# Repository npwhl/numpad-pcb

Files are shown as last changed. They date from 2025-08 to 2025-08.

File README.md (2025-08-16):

# 6x4 USB-C Numpad PCB
A PCB for a 6x4 numpad with a row for four customizable macros. Uses Alps switch footprints and a USB-C connection. Designed in Kicad.    

TBA: an image of the final PCB in person! :-)   
Gif of the PCB    
TBA: link to firmware repository   

# The Design
_A schematic of the MCU connections._  
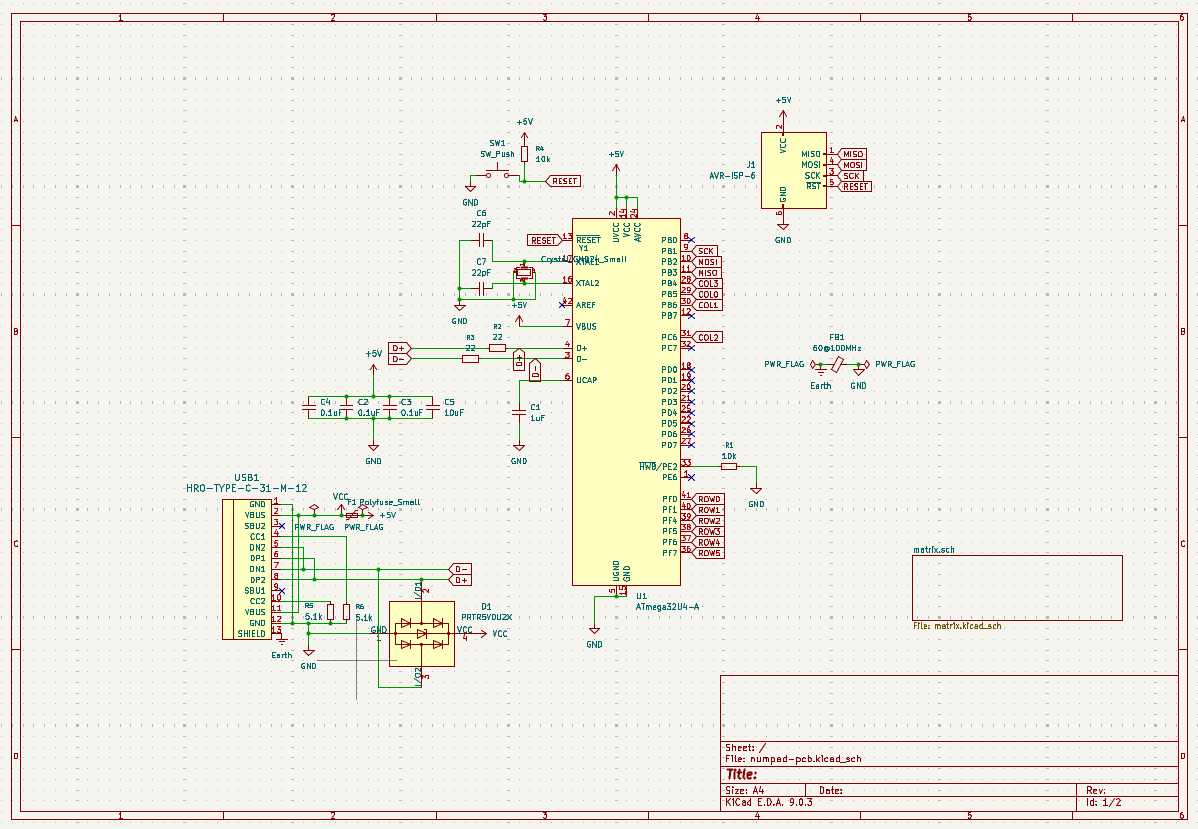
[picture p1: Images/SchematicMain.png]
Schematic of the MCU


_A schematic of the matrix of switch connections._    
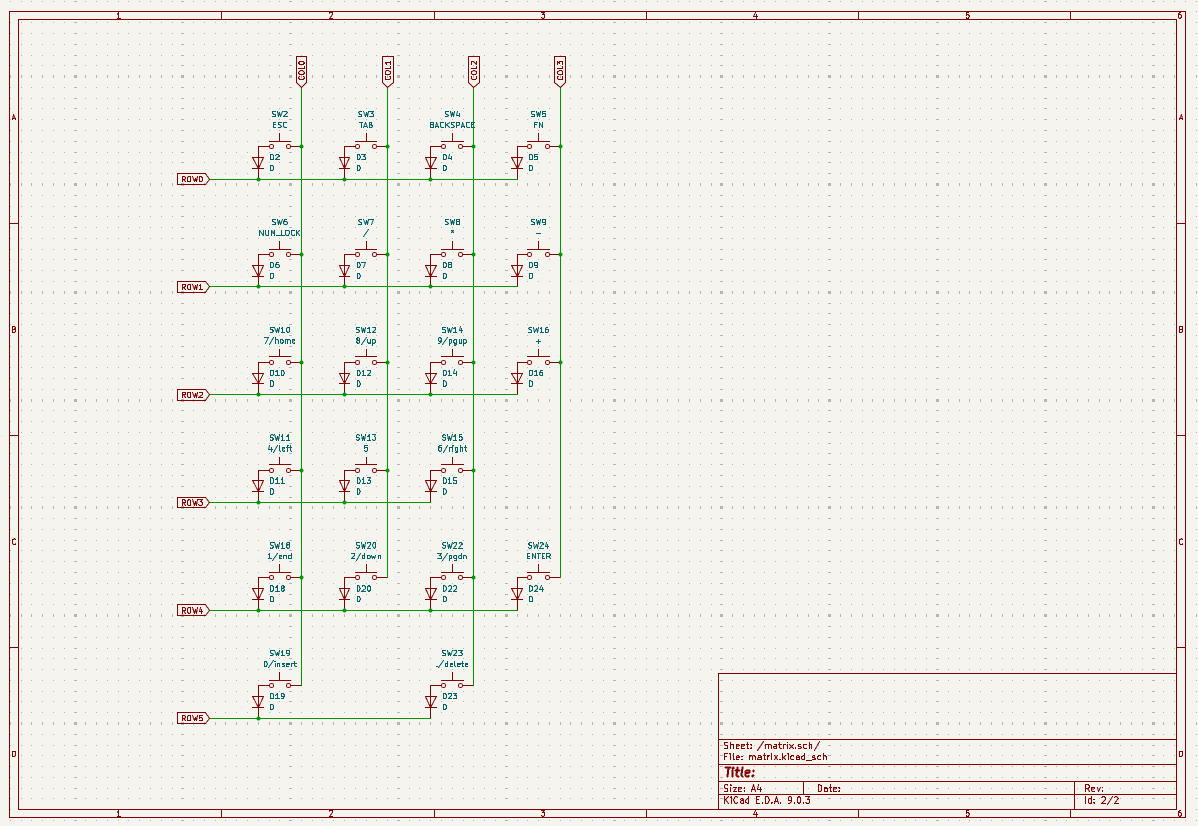
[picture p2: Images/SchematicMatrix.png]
Schematic of the Switches Matrix
   

_The front traces of the PCB._      
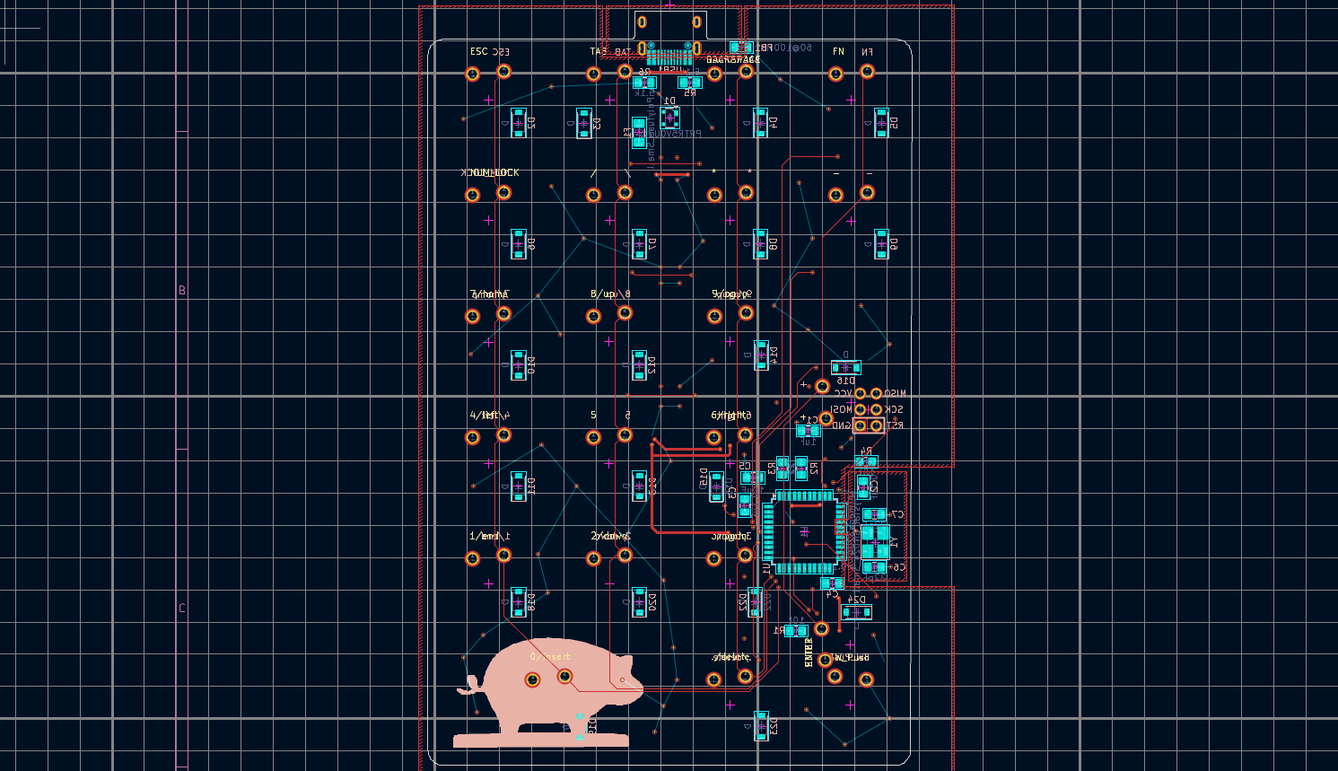
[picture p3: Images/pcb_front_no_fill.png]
     

_The back traces of the PCB._      
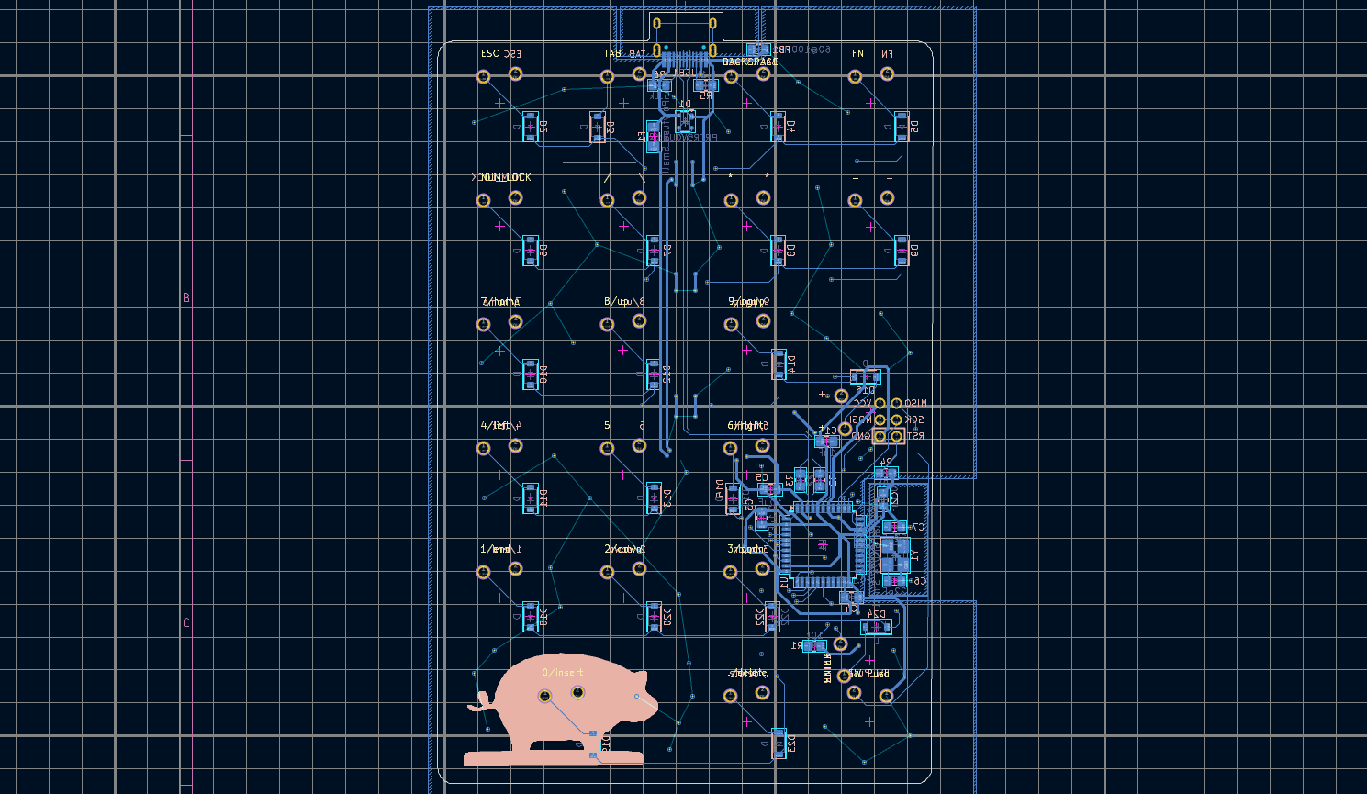
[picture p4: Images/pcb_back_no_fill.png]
     

# How It Was Made
**Software:** Kicad EDA v9.03  
**Manufacturer:** TBA  
This numpad uses the following bill of materials:    
| Designation | Type | Footprint | Quantity |
|---|---|---|---|
| FB1 | Ferrite Bead | 0805 | 1 |
| SW1 | Reset switch | SKQG | 1 |
| SW2-SW23 | Reset switch | ALPS | 22 |
| C1-C4 | 100nF Capacitor | 0805 | 4 |
| C5 | 10uF Capacitor | 0805 | 1 |
| C6 | 1uF Capacitor | 0805 | 1 |
| C7, C8 | 22pF Capacitor | 0805 | 2 |
| R1, R2 | 10kΩ Resistor | 0805 | 2 |
| R3, R4 | 22Ω Resistor | 0805 | 2 |
| R5, R6 | 5.1kΩ Resistor | 0805 | 2 |
| X1 | 16 MHz Crystal | 3225 | 1 |
| USB1 | USB Connector | HRO-TYPE-C-31-M-12 | 1  |
| U2 | PRTR5V0U2X | SOT143B | 1 |
| U1 | Atmega 32U4-AU | TQFP-44 | 1 |
| F1 | PTC Fuse | 1206 | 1 |
| D1-D23 | Diode | SOD-123 | 23 | 
   
The 3D modeling software Blender has many shortcuts that are only accessable using numpad shortcuts. Although these features are also accessable on Blender's UI, these shortcuts greatly accelerate the modeling process. However, my partner's keyboard is 65% and lacks a numpad. I wanted to design him a numpad that could solve this problem while using the keycaps and Alps switches he currently had. I also wanted to design the numpad with USB-C conectivity and a 4-key macro row for any additional shortcuts.  
  
To make the numpad, I followed [Masterzen's tutorial](https://www.masterzen.fr/2020/05/03/designing-a-keyboard-part-1/) on designing a PCB for a keyboard. This was my first time designing a PCB and using software like Kicad. I initially struggled with laying out the components on the PCB. I learned a lot of new information about why PCB components are laid out in specific ways and how to handle signals with minimal noise. I also learned about the importance of impedance on especially delicate routes such as the USB-C's D+/D- differential pair. In the future, I would like to optimize routing as much as possible with minimal vias. The amount of traces and their angles around the MCU are somewhat difficult to read and has the potential to create too much noise around the critical differential pairs. Since this is a low-speed numpad, this will most likely not be an issue, but I want to prioritize reliable PCB design moving forward.
      
_The PCB as viewed in the 3D viewer._      
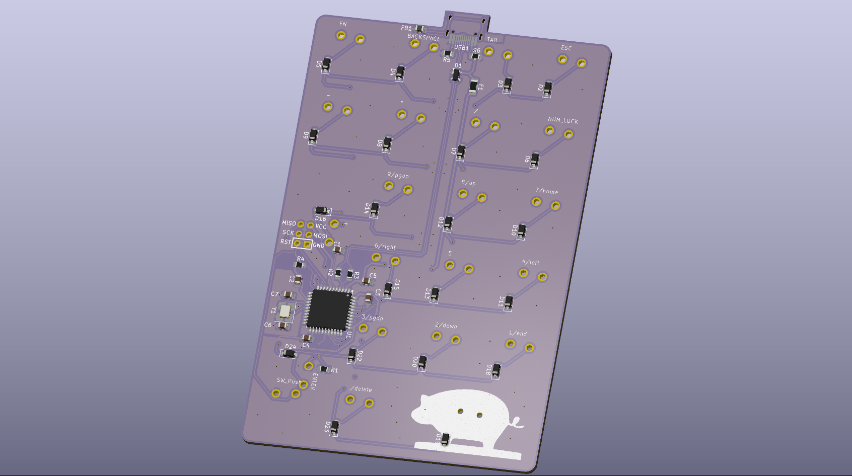
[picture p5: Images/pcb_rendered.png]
     

# To Do
This PCB is still in progress. The next steps are:  
1. Order PCB board and its components. 
2. Program the firmware using [QMK](https://github.com/qmk/qmk_firmware). 
3. Model a chassis for the numpad in Solidworks. 
4. Create a main repository where the final design is kept. 

# How to Build
If you want to build the numpad yourself, you can order the parts following the links on the bill of materials table above! You can also use the same manufacturer, or the following Kicad-recommended manufacturers:  
* [Alsier (US)](https://aisler.net/)
* [OSHPark (US)](https://docs.oshpark.com/design-tools/kicad/generating-kicad-gerbers/)
* [PCBWay (China)](https://www.pcbway.com/blog/help_center/Generate_Gerber_file_from_Kicad.html)

<sub><sup>PS: Thank you (bf's github user)!</sup></sub>

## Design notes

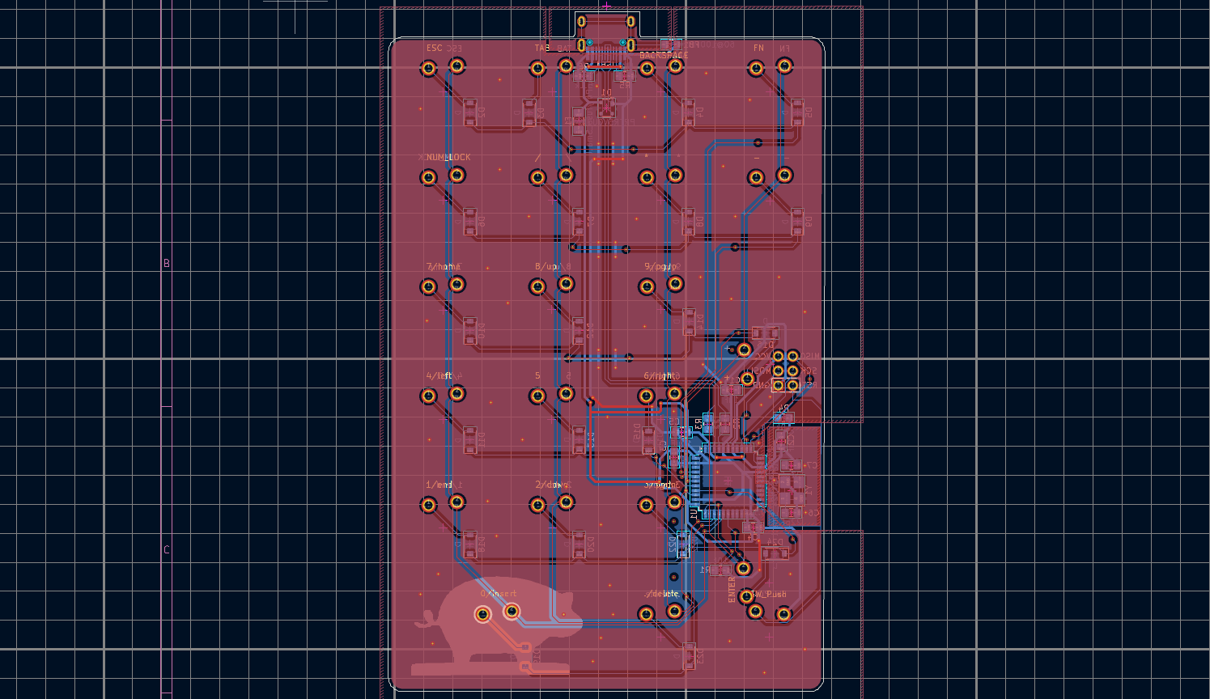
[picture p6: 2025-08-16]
Images/pcb_fill.png

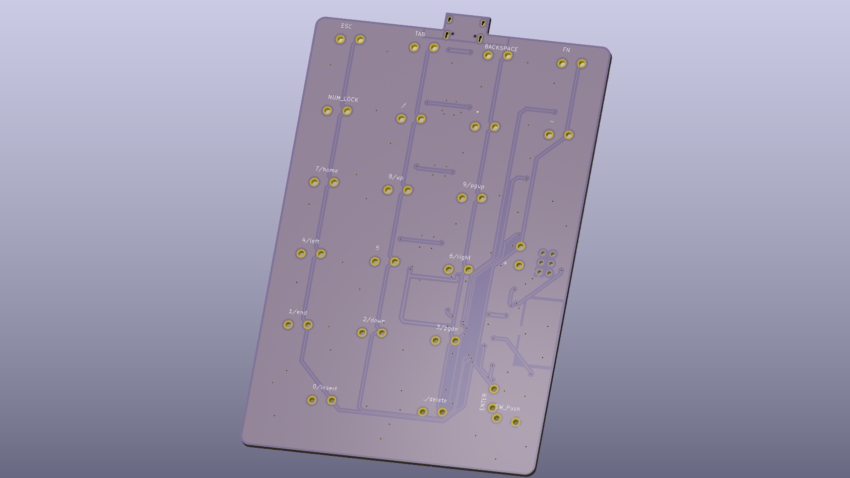
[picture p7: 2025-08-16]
Images/pcb_rendered_back.png

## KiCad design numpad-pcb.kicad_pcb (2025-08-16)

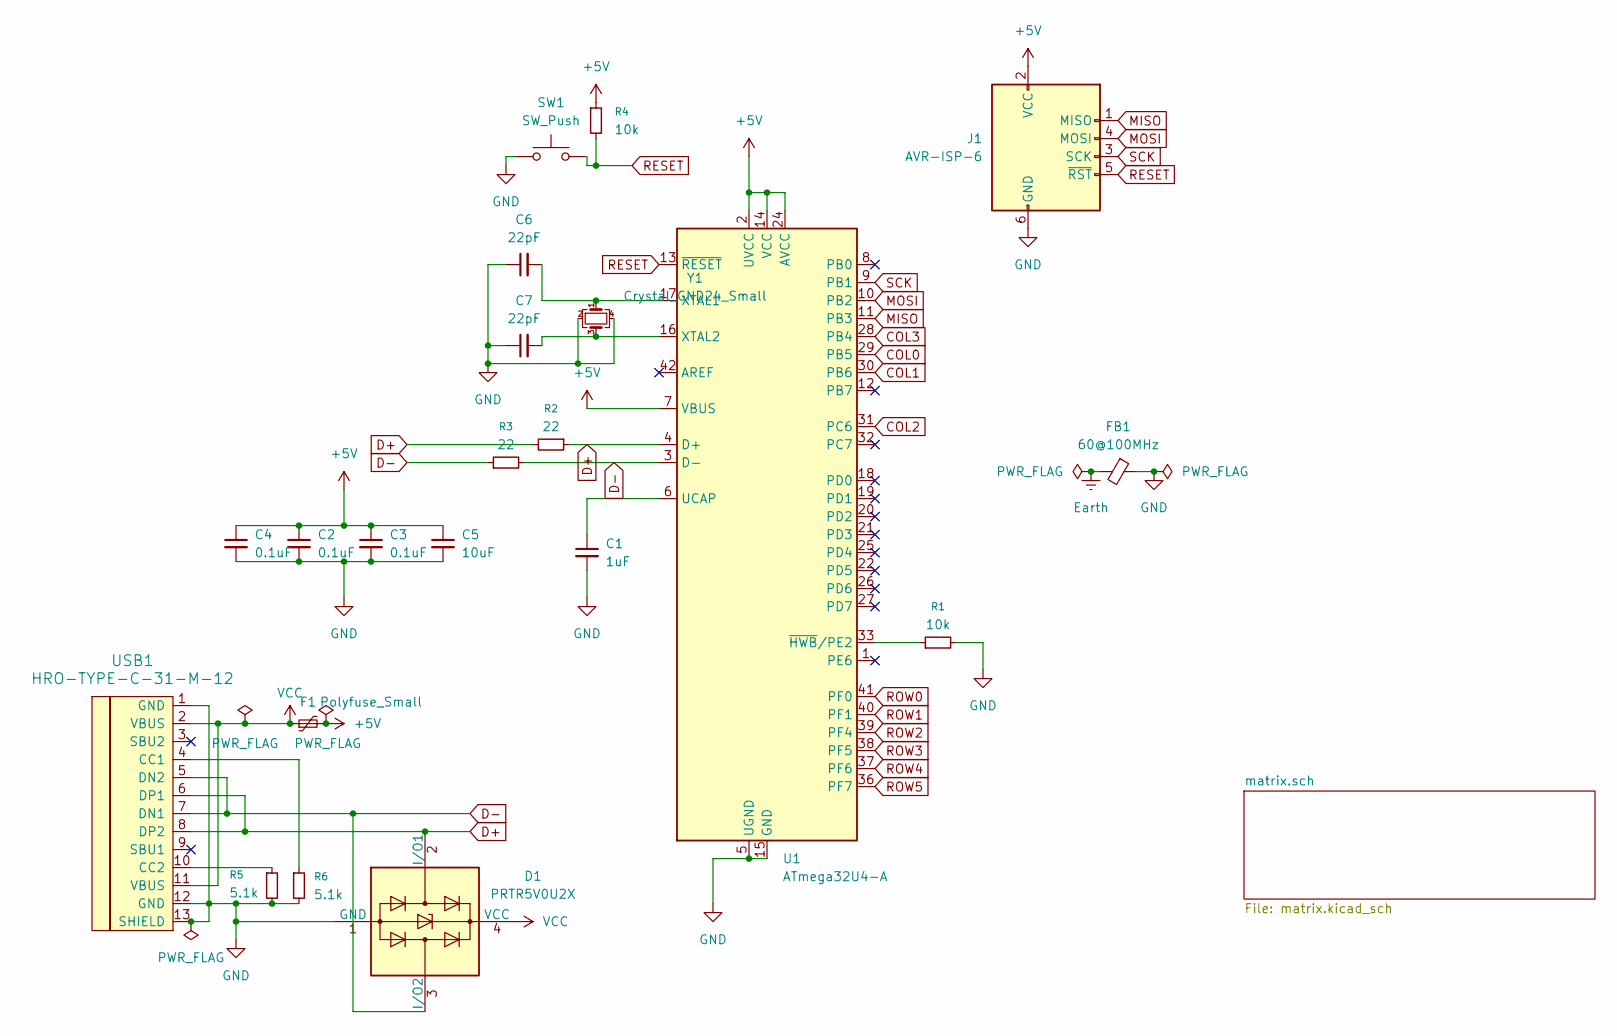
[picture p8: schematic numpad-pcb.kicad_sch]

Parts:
C1: 1uF; C_0805_2012Metric_Pad1.18x1.45mm_HandSolder
C2, C3, C4: 0.1uF; C_0805_2012Metric_Pad1.18x1.45mm_HandSolder
C5: 10uF; C_0805_2012Metric_Pad1.18x1.45mm_HandSolder
C6, C7: 22pF; C_0805_2012Metric_Pad1.18x1.45mm_HandSolder
D1: PRTR5V0U2X; SOT-143
F1: Polyfuse_Small; Fuse_1206_3216Metric_Pad1.42x1.75mm_HandSolder
FB1: 60@100MHz; L_0805_2012Metric_Pad1.15x1.40mm_HandSolder
J1: AVR-ISP-6; Reset_Pretty-Mask
R1, R4: 10k; R_0805_2012Metric_Pad1.20x1.40mm_HandSolder
R2, R3: 22; R_0805_2012Metric_Pad1.20x1.40mm_HandSolder
R5, R6: 5.1k; R_0805_2012Metric_Pad1.20x1.40mm_HandSolder
SW1: SW_Push; ALPS-1U
U1: ATmega32U4-A; TQFP-44_10x10mm_P0.8mm
USB1: HRO-TYPE-C-31-M-12; HRO-TYPE-C-31-M-12-HandSoldering
Y1: Crystal_GND24_Small; Crystal_SMD_3225-4Pin_3.2x2.5mm_HandSoldering

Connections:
+5V: C2.1, C3.1, C4.1, C5.1, F1.2, J1.2 (VCC), R4.1, U1.2 (UVCC), U1.7 (VBUS), U1.14 (VCC), U1.24 (AVCC), U1.34 (VCC), U1.44 (AVCC)
COL0: U1.29 (PB5); also elsewhere on the board
COL1: U1.30 (PB6); also elsewhere on the board
COL2: U1.31 (PC6); also elsewhere on the board
COL3: U1.28 (PB4); also elsewhere on the board
D+: D1.2 (I/O1), R2.1, R2.2, U1.4 (D+), USB1.6 (DP1), USB1.8 (DP2)
D-: D1.3 (I/O2), R3.1, R3.2, U1.3 (D-), USB1.5 (DN2), USB1.7 (DN1)
MISO: J1.1 (MISO), U1.11 (PB3)
MOSI: J1.4 (MOSI), U1.10 (PB2)
unnamed: C1.1, U1.6 (UCAP)
unnamed: C6.2, U1.17 (XTAL1), Y1.1
unnamed: C7.2, U1.16 (XTAL2), Y1.3
unnamed: R1.1, U1.33 (~HWB/PE2)
unnamed: R6.1, USB1.4 (CC1)
unnamed: R5.1, USB1.10 (CC2)
RESET: J1.5 (~RST), R4.2, SW1.2, U1.13 (~RESET)
ROW0: U1.41 (PF0); also elsewhere on the board
ROW1: U1.40 (PF1); also elsewhere on the board
ROW2: U1.39 (PF4); also elsewhere on the board
ROW3: U1.38 (PF5); also elsewhere on the board
ROW4: U1.37 (PF6); also elsewhere on the board
ROW5: U1.36 (PF7); also elsewhere on the board
SCK: J1.3 (SCK), U1.9 (PB1)
VCC: D1.4 (VCC), F1.1, USB1.2 (VBUS), USB1.11 (VBUS)

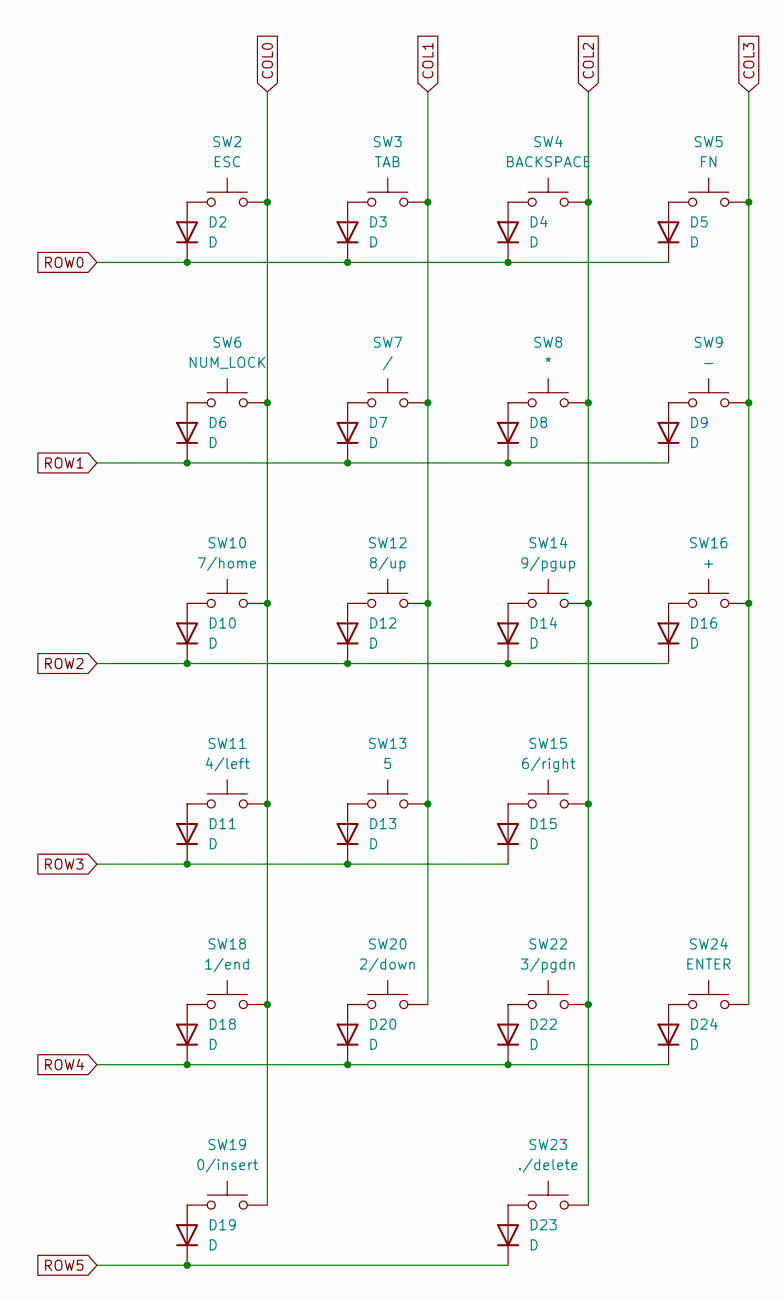
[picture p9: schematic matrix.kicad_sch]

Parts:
D2, D3, D4, D5, D6, D7, D8, D9, D10, D11, D12, D13, D14, D15, D16, D18, D19, D20, D22, D23, D24: D; D_SOD-123
SW2: ESC; ALPS-1U
SW3: TAB; ALPS-1U
SW4: BACKSPACE; ALPS-1U
SW5: FN; ALPS-1U
SW6: NUM_LOCK; ALPS-1U
SW7: /; ALPS-1U
SW8: *; ALPS-1U
SW9: -; ALPS-1U
SW10: 7/home; ALPS-1U
SW11: 4/left; ALPS-1U
SW12: 8/up; ALPS-1U
SW13: 5; ALPS-1U
SW14: 9/pgup; ALPS-1U
SW15: 6/right; ALPS-1U
SW16: +; ALPS-2U
SW18: 1/end; ALPS-1U
SW19: 0/insert; ALPS-2U
SW20: 2/down; ALPS-1U
SW22: 3/pgdn; ALPS-1U
SW23: ./delete; ALPS-1U
SW24: ENTER; ALPS-2U

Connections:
COL0: SW2.2, SW6.2, SW10.2, SW11.2, SW18.2, SW19.2; also elsewhere on the board
COL1: SW3.2, SW7.2, SW12.2, SW13.2, SW20.2; also elsewhere on the board
COL2: SW4.2, SW8.2, SW14.2, SW15.2, SW22.2, SW23.2; also elsewhere on the board
COL3: SW5.2, SW9.2, SW16.2, SW24.2; also elsewhere on the board
unnamed: D2.2 (A), SW2.1
unnamed: D3.2 (A), SW3.1
unnamed: D4.2 (A), SW4.1
unnamed: D5.2 (A), SW5.1
unnamed: D6.2 (A), SW6.1
unnamed: D7.2 (A), SW7.1
unnamed: D8.2 (A), SW8.1
unnamed: D9.2 (A), SW9.1
unnamed: D10.2 (A), SW10.1
unnamed: D11.2 (A), SW11.1
unnamed: D12.2 (A), SW12.1
unnamed: D13.2 (A), SW13.1
unnamed: D14.2 (A), SW14.1
unnamed: D15.2 (A), SW15.1
unnamed: D16.2 (A), SW16.1
unnamed: D18.2 (A), SW18.1
unnamed: D19.2 (A), SW19.1
unnamed: D20.2 (A), SW20.1
unnamed: D22.2 (A), SW22.1
unnamed: D23.2 (A), SW23.1
unnamed: D24.2 (A), SW24.1
ROW0: D2.1 (K), D3.1 (K), D4.1 (K), D5.1 (K); also elsewhere on the board
ROW1: D6.1 (K), D7.1 (K), D8.1 (K), D9.1 (K); also elsewhere on the board
ROW2: D10.1 (K), D12.1 (K), D14.1 (K), D16.1 (K); also elsewhere on the board
ROW3: D11.1 (K), D13.1 (K), D15.1 (K); also elsewhere on the board
ROW4: D18.1 (K), D20.1 (K), D22.1 (K), D24.1 (K); also elsewhere on the board
ROW5: D19.1 (K), D23.1 (K); also elsewhere on the board

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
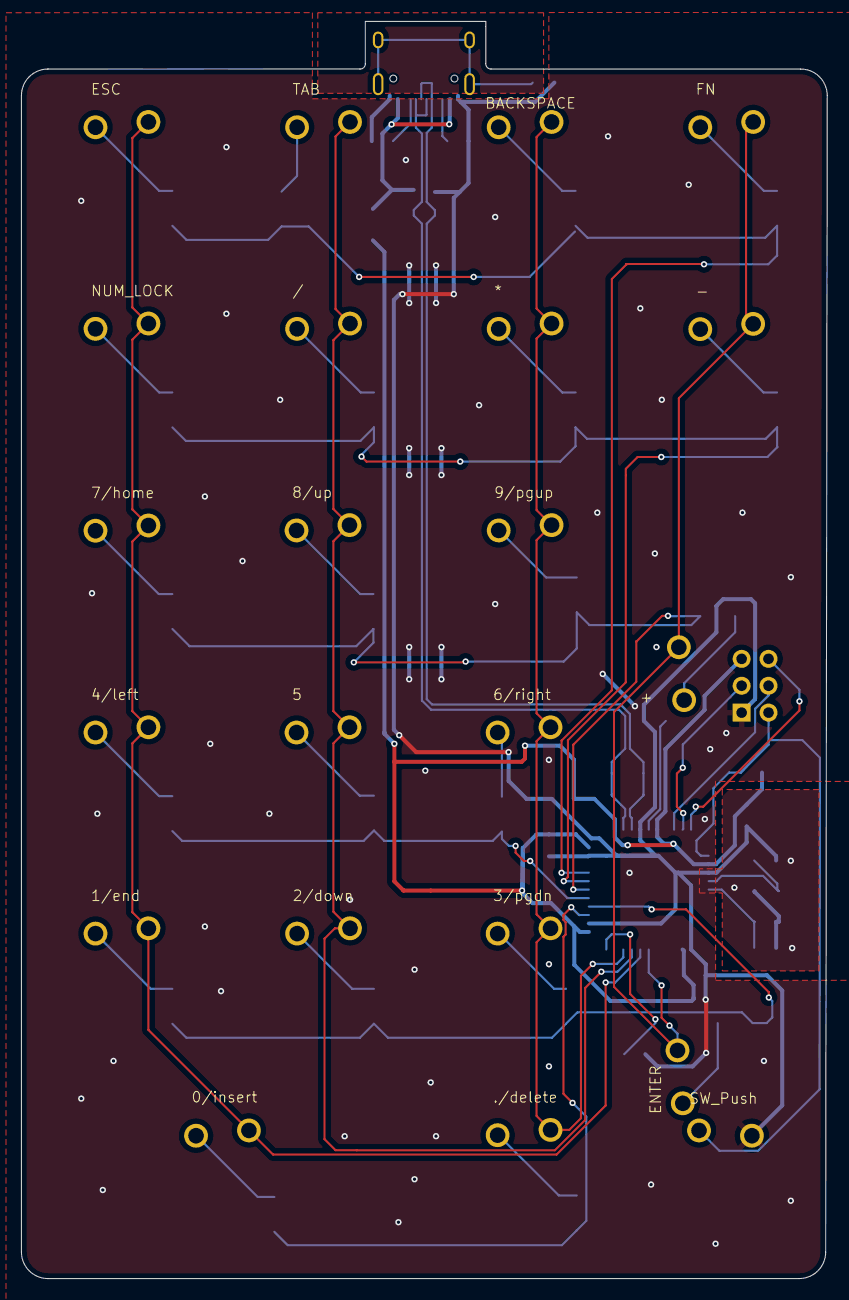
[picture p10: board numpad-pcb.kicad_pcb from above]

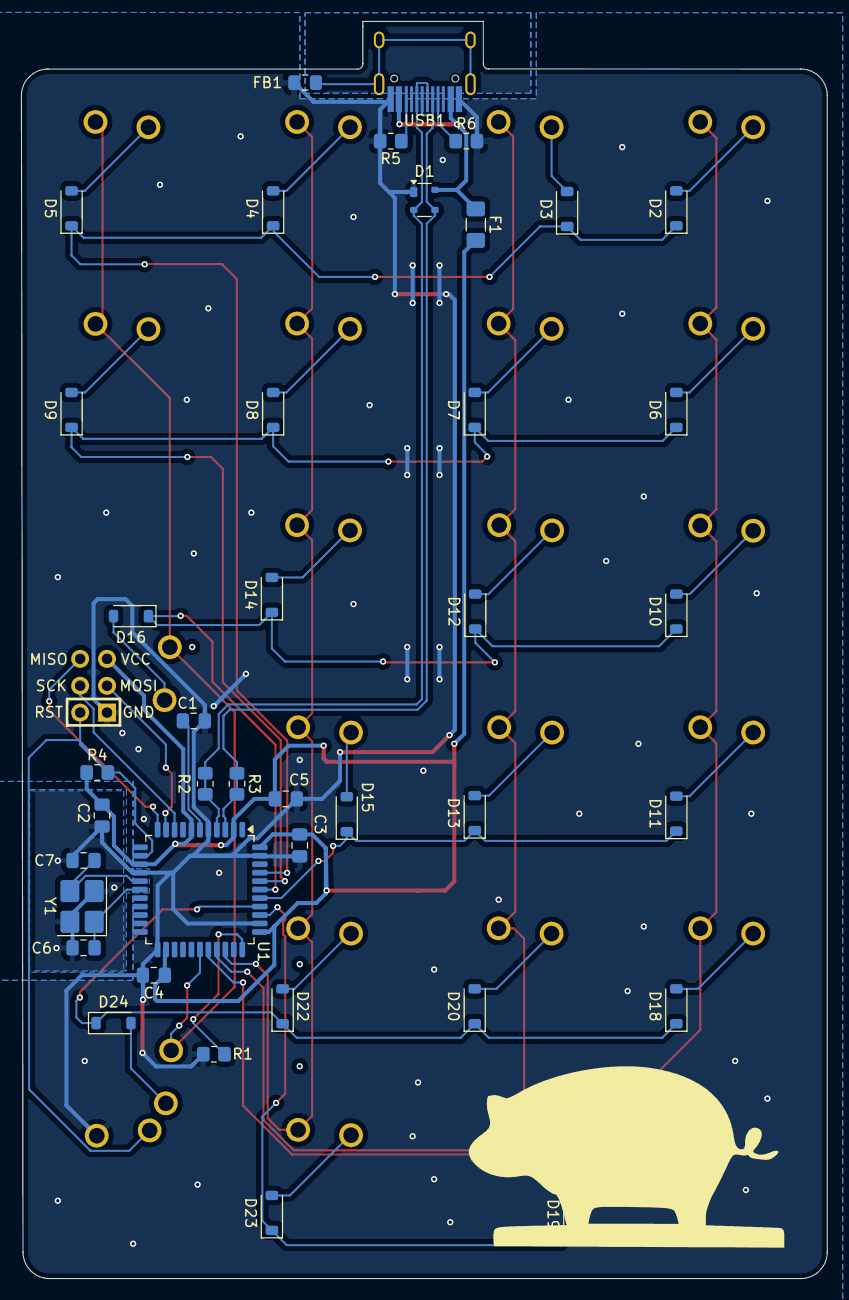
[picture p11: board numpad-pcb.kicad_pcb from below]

Board: 2 copper layers, 76.2 x 118.8 mm, 63 parts (42 on the bottom side), 47 nets.

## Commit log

2025-08-03 Incude submodules in Kicad
2025-08-03 Complete MCU schematic
    [numpad-pcb.kicad_sch]
2025-08-07 Add USB-C and reset schematic
    [numpad-pcb.kicad_sch]
2025-08-07 Create numpad matrix
    [matrix.kicad_sch, numpad-pcb.kicad_sch]
2025-08-07 Fix schematic based on ERC
    [matrix.kicad_sch, numpad-pcb.kicad_sch]
2025-08-13 Update PCB to show schematic changes
    [matrix.kicad_sch, numpad-pcb.kicad_pcb, numpad-pcb.kicad_sch]
2025-08-13 Correct PCB footprints
    [matrix.kicad_sch, numpad-pcb.kicad_pcb]
2025-08-14 Initial layout of PCB components
    [numpad-pcb.kicad_pcb]
2025-08-14 Fix silkscreen errors
    [numpad-pcb.kicad_pcb]
2025-08-14 Update USB-C 3D model
    [numpad-pcb.kicad_pcb]
2025-08-14 Repair edge and bottom traces
    Fixed the differential pair to have closer trace lengths (+/- 0.5 mm
    reduced to 0.03 mm) for higher accuracy and error prevention. Also
    created GND pour for crystal to reduce noise.
    [numpad-pcb.kicad_pcb, numpad-pcb.kicad_sch]
2025-08-14 Routed power
    [numpad-pcb.kicad_pcb]
2025-08-15 Update README with images
    [numpad-pcb.kicad_sch]
2025-08-15 Fix image captions in README
    [numpad-pcb.kicad_sch]
2025-08-15 Finish traces and start silkscreen
    Still need to modify traces to be more optimal and increase readibility.
    Also updated silkscreen preferences locally to have the label of each
    switch on both the front and back of the PCB. Need to make a note that
    this change is local because of the submodule imported from the start.
    [numpad-pcb.kicad_pcb, numpad-pcb.kicad_sch]
2025-08-15 Decorate PCB
    [numpad-pcb.kicad_pcb]
2025-08-15 Add copper ground pour
    [numpad-pcb.kicad_pcb]
2025-08-15 Restore schematic backup
2025-08-16 Add USB-C shield protection
    Changed the USB-C shield from being connected to ground to being
    connected to a ferrite bead low pass filter to manage ESD. Also adjusted
    ground around USB to prevent ESD from damaging nearby components.
    [numpad-pcb.kicad_pcb, numpad-pcb.kicad_sch]
